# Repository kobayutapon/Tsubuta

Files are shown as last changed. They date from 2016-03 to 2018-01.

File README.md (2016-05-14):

# Tsubuta
Tsubuta is IoT device produced by GDG Shinshu

## Presentation
* [Presentation Document](./Document/Tsubuta_Presentation.pdf.pdf)

## Hardware Information  
* [Hardware Specification](./Hardware/BoardSpec.md)
* [Board schematic](./Hardware/Tsubuta_Schematic.pdf)
* [Firmware](./Hardware/Arduino/Tsubuta_AddOnBoard/Tsubuta_AddOnBoard.ino)

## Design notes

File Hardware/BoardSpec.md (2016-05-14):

# つぶ田 Add-On ボード仕様
## Hardware
* Arduino互換　ATMega328P
* 外部I/F
 I2C/UART(Arduino)/UART(Raspberry Pi)

### EEPROM 仕様
|Address|Description|
|:---|-----|
|00h | Version. if 0xff, value is not set.|
|01h | Power On Mode : 0 - auto power off / 1 : auto power on |  
|02h/03h/04h/05h  | Interval Timer Count |
|06h | GPIO0 Setting 0:Out / 1:In / 2:In-Pullup |
|07h | GPIO1 Setting 0:Out / 1:In / 2:In-Pullup |
|08h | GPIO2 Setting 0:Out / 1:In / 2:In-Pullup |
|09h | GPIO3 Setting 0:Out / 1:In / 2:In-Pullup |

### GPIO Pin assign
|Port|Pin No.|Description|
|:---|---|---|
|TSUBUTA_UART_RXD  | 0 |  PD0 |
|TSUBUTA_UART_TXD  | 1 |  PD1 |
|TSUBUTA_RPIPOWER  | 3 |  PD3 (O)  Raspberry Pi Power On/Off |
|TSUBUTA_GPI_POFF  | 4 |  PD4 (I) Shutdown signal from Raspberry Pi |
|TSUBUTA_GPIO0 | 5 |  PD5  PWM |
|TSUBUTA_GPIO1 | 6 |  PD6  PWM |
|TSUBUTA_GPIO2 | 7 |  PD7 |
|TSUBUTA_GPIO3 | 8 |  PB0 |
|TSUBUTA_RPI_INT | 9 |  PB1 (O) Interrupt signal to Raspberry Pi |
|TSUBUTA_RTC_INT | 10 |  PB2 (I) Interrupt signal from DS1307(RTC Clock) |
|TSUBUTA_AD0 | A0  |  PC0 |
|TSUBUTA_AD1 | A1  |  PC1 |
|TSUBUTA_AD2 | A2  |  PC2 |
|TSUBUTA_AD3 | A3  |  PC3 |

## Firmware仕様

### I/F
* I2C
Slave Address 0x08  
Raspberry Piと接続。電源は3.3V。  

### プログラム仕様
#### I2C Command一覧  

|Command|Parameter|Length|Decsription|
|:---|---|---|---|
| 0x00 | N/A | 0x01 | Get Baord Information |
| 0x01 | Time(4Byte)| 0x05 | Set Interval Timer |
| 0x02 | N/A | 0x01 | RPi Power Off |
| 0x0F | N/A | 0x01 | Save settings to EEPROM |
| 0x10 | State ( 1Byte) |0x02| Set GPIO1 State|
| 0x11 | State ( 1Byte) |0x02| Set GPIO2 State|
| 0x12 | State ( 1Byte) |0x02| Set GPIO3 State|
| 0x13 | State ( 1Byte) |0x02| Set GPIO4 State|
| 0x20 | H/L ( 1Byte) | 0x02 | Set GPO1 H/L |
| 0x21 | H/L ( 1Byte) | 0x02 | Set GPO2 H/L |
| 0x22 | H/L ( 1Byte) | 0x02 | Set GPO3 H/L |
| 0x23 | H/L ( 1Byte) | 0x02 | Set GPO4 H/L |
| 0x30 | H/L ( 1Byte) | 0x02 | Get GPI1 |
| 0x31 | H/L ( 1Byte) | 0x02 | Get GPI2 |
| 0x32 | H/L ( 1Byte) | 0x02 | Get GPI3 |
| 0x33 | H/L ( 1Byte) | 0x02 | Get GPI4 |
| 0x40 | N/A | 0x01 | Get ADC1 |
| 0x41 | N/A | 0x01 | Get ADC2 |
| 0x42 | N/A | 0x01 | Get ADC3 |
| 0x43 | N/A | 0x01 | Get ADC4 |

#### Command詳細
* ボード情報取得(0x00)  
FWのVersion情報を取得する。コマンド実行例をいかに示す。
```
root@raspberrypi:/home/pi# i2cget -y 1 0x08 0x00
0x01
```

* 起動時間間隔設定(0x01)  
自動起動の間隔を秒単位で指定する。指定は4バイトで秒単位で指定する。
```
i2cset -y 1 0x08 0x01 0x00 0x00 0x00 0xff i
```

* 起動時間間隔設定(0x02)  
Raspberry Piの電源をOFFにする。
```
i2cset -y 1 0x08 0x02
```

## Raspberry Piからの制御例
### i2ctoolsを使う場合
* Inerval Timerの設定
```
i2cset 1 0x08 0x01 0x00 0x00 0x00 0xff i
```

* EEPROMの保存
```
i2cset 1 0x08 0x0F
```

### GPIOの制御
GPIO経由で電源を切るには以下のコマンドを実行する。  

```
echo 17 > /sys/class/gpio/export
echo out > /sys/class/gpio/gpio17/direction
echo 1 > /sys/class/gpio/gpio17/value
```

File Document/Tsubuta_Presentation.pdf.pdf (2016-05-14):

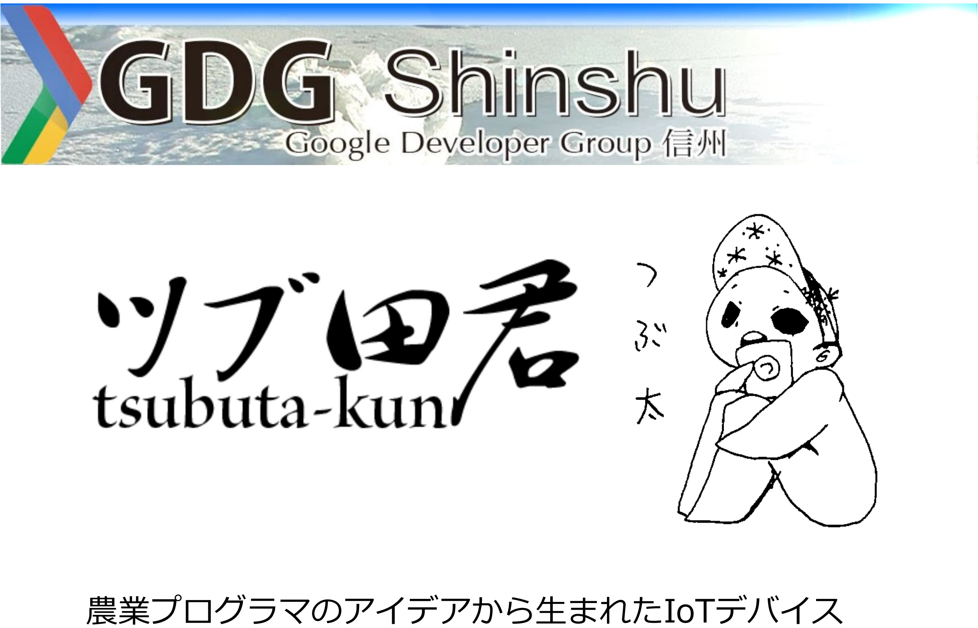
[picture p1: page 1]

## 農業プログラマのアイデアから生まれたIoTデバイス

農家やってると
・朝早く田んぼ見に行かなきゃいけないのよ。。。4時とかなｗ ・田んぼ、遠いんだよ。。。２ｋｍとか普通に離れてる。。。 ・必要な時だけいきたいんだよー！！
という悩みがあるので作りました。
特徴
・Raspberry Piと3G USB通信モデムを使って呟きます。 ・独自の電源制御基板で省電力。5V 2500mAhのバッテリーなら1日1回の つぶやきで三か月くらいは持ちます。
・材料は塩ビパイプで構成。防水も行けます。

## なんで作ったの？

### 畑に設置した様子

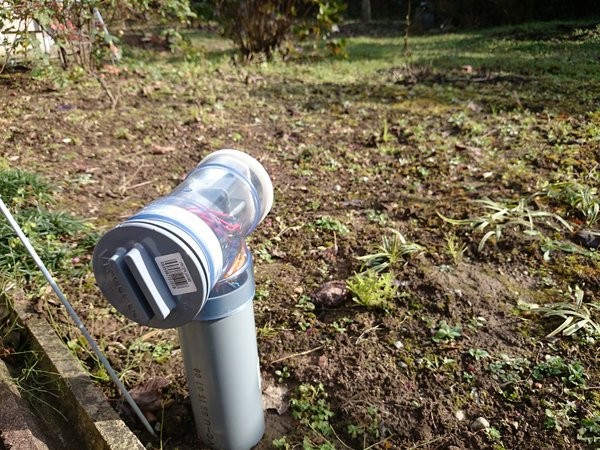
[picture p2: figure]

### つぶ田くん システムブロック図

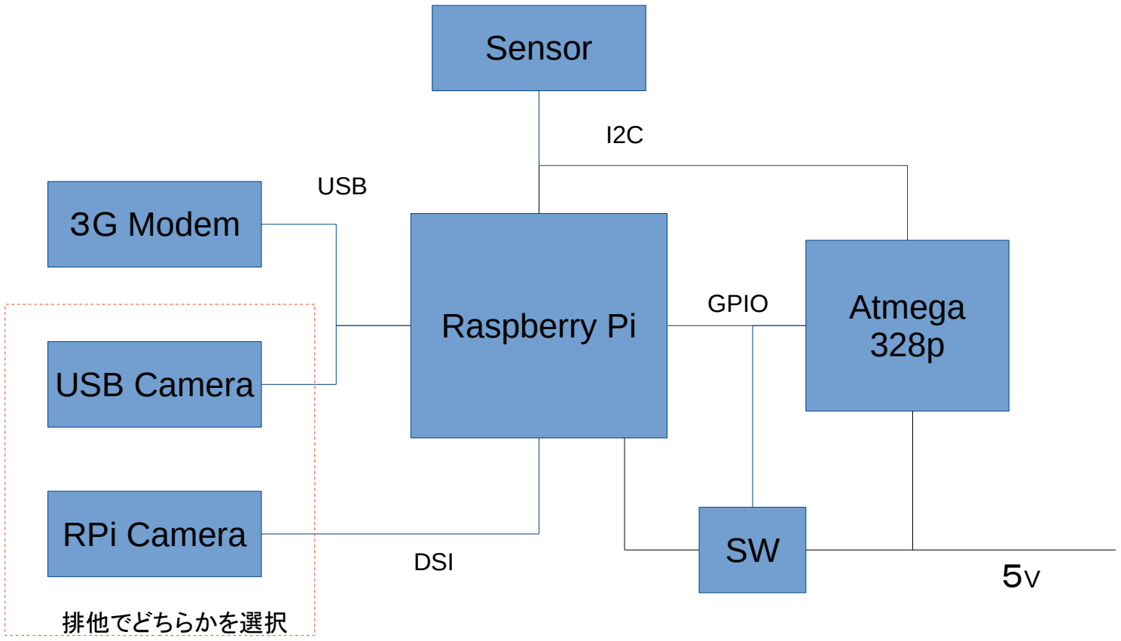
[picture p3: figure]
Raspberry Pi; ３G Modem; USB Camera; RPi Camera; Atmega 328p; Sensor; USB; GPIO; DSI; 排他でどちらかを選択

### 設定方法 Google Spreadsheetsを編集するだけ！

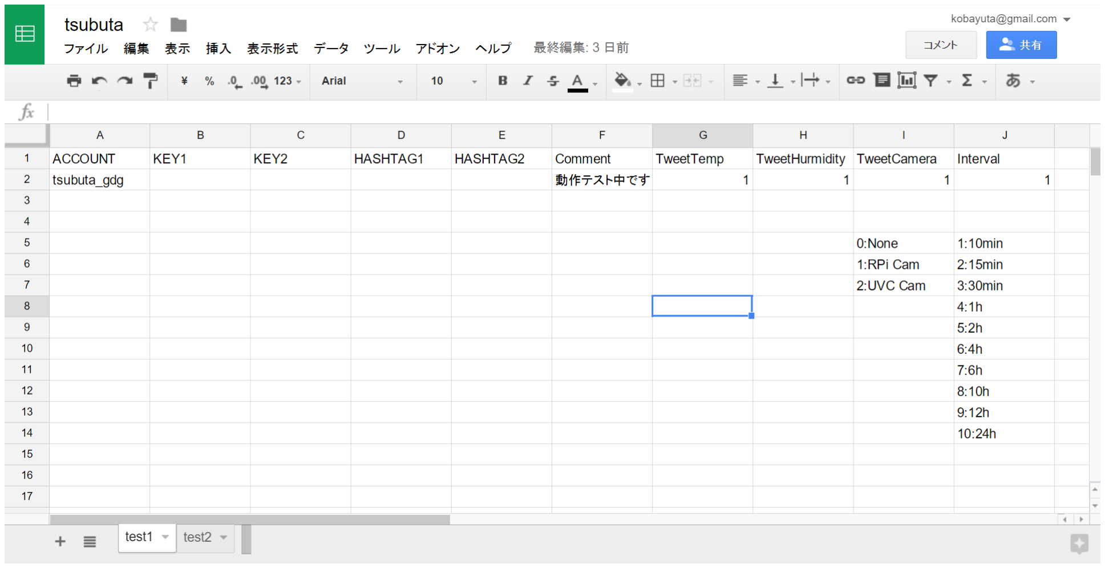
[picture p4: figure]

### 設定時間ごとに呟きます

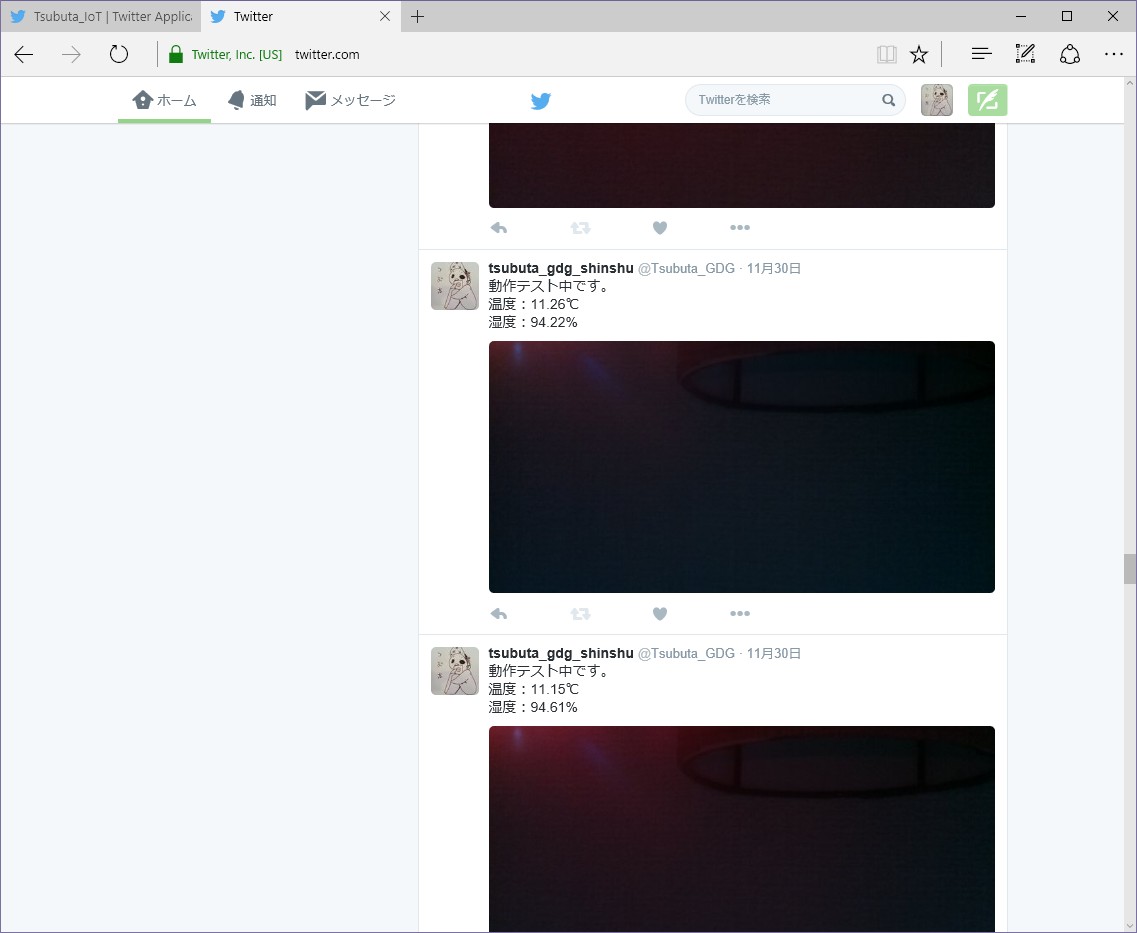
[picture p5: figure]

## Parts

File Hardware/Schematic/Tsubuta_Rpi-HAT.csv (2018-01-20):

Reference | Value | Footprint | Datasheet
C1 | 0.1uF | Capacitors_SMD:C_0805_HandSoldering
C2 | 22pF | Capacitors_SMD:C_0805_HandSoldering
C3 | 22pF | Capacitors_SMD:C_0805_HandSoldering
C4 | 0.33uF | Capacitors_SMD:C_0805_HandSoldering
C5 | 22uF | Capacitors_SMD:C_0805_HandSoldering
C6 | 2.2uF | Capacitors_SMD:C_0805_HandSoldering
J1 | Conn_01x04 | Pin_Headers:Pin_Header_Straight_1x04_Pitch2.54mm
J10 | CN_I2C | Pin_Headers:Pin_Header_Straight_1x04_Pitch2.54mm
J11 | ADC0 | Pin_Headers:Pin_Header_Straight_1x03_Pitch2.54mm
J12 | ADC1 | Pin_Headers:Pin_Header_Straight_1x03_Pitch2.54mm
J13 | ADC2 | Pin_Headers:Pin_Header_Straight_1x03_Pitch2.54mm
J14 | ADC3 | Pin_Headers:Pin_Header_Straight_1x03_Pitch2.54mm
J15 | BOOTMODE | Pin_Headers:Pin_Header_Straight_2x05_Pitch2.54mm
J2 | RPi_GPIO | RPi_Hat:Pin_Header_Straight_2x20
J3 | CN_ICSP | Pin_Headers:Pin_Header_Straight_2x03_Pitch2.54mm
J4 | Jack-DC | Connect:BARREL_JACK
J5 | GPIO0 | Pin_Headers:Pin_Header_Straight_1x03_Pitch2.54mm
J6 | GPIO1 | Pin_Headers:Pin_Header_Straight_1x03_Pitch2.54mm
J7 | GPIO2 | Pin_Headers:Pin_Header_Straight_1x03_Pitch2.54mm
J8 | GPIO3 | Pin_Headers:Pin_Header_Straight_1x03_Pitch2.54mm
J9 | Conn_01x03 | Pin_Headers:Pin_Header_Straight_1x03_Pitch2.54mm
Q1 | 2SC3325-Y | TO_SOT_Packages_SMD:SC-59_Handsoldering
Q2 | IRLML6402(SOT-23) | TO_SOT_Packages_SMD:SOT-23_Handsoldering
R1 | 10K | Resistors_SMD:R_0805_HandSoldering
R10 | 1K | Resistors_SMD:R_0805_HandSoldering
R11 | 10K | Resistors_SMD:R_0805_HandSoldering
R12 | 10K | Resistors_SMD:R_0805_HandSoldering
R13 | 10K | Resistors_SMD:R_0805_HandSoldering
R14 | 1.8K | Resistors_SMD:R_0805_HandSoldering
R15 | 3.3K | Resistors_SMD:R_0805_HandSoldering
R2 | 10K | Resistors_SMD:R_0805_HandSoldering
R3 | 10K | Resistors_SMD:R_0805_HandSoldering
R4 | 10K | Resistors_SMD:R_0805_HandSoldering
R5 | 10K | Resistors_SMD:R_0805_HandSoldering
R6 | 10K | Resistors_SMD:R_0805_HandSoldering
R7 | 10K | Resistors_SMD:R_0805_HandSoldering
R8 | 10K | Resistors_SMD:R_0805_HandSoldering
R9 | 10K | Resistors_SMD:R_0805_HandSoldering
SW1 | SW_RST | Buttons_Switches_THT:SW_PUSH_6mm
U1 | ATMEGA328P-AU | Housings_QFP:TQFP-32_7x7mm_Pitch0.8mm
U2 | NJM2884U1 | TO_SOT_Packages_SMD:SOT-89-5_Housing_Handsoldering
Y1 | 16MHz | Crystals:Crystal_HC49-U_Vertical

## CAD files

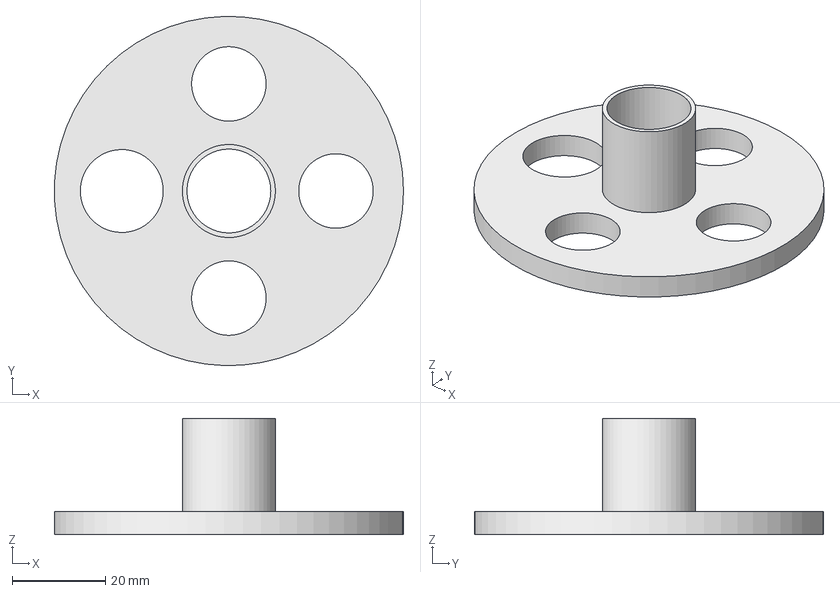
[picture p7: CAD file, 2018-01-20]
Hardware/Mecha/Tsubuta_Sensor_Holder.FCStd
74.9 x 75.0 x 25.0 mm

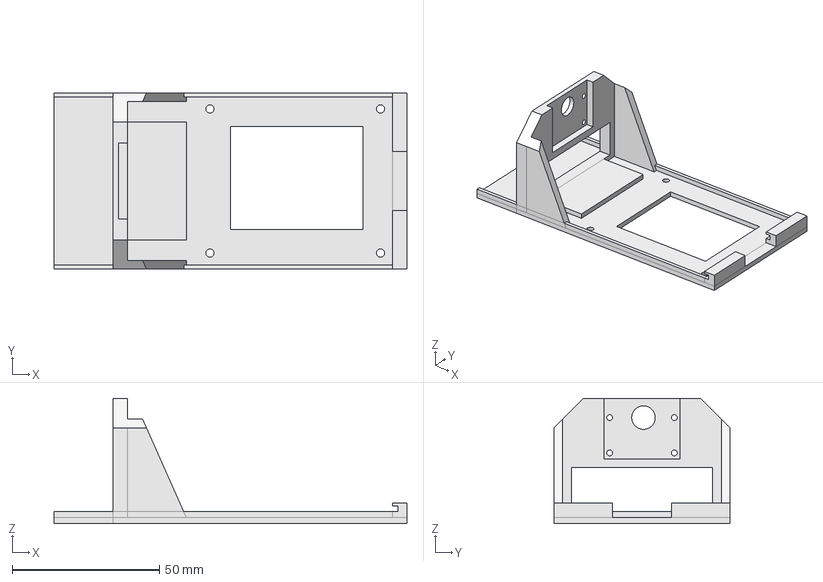
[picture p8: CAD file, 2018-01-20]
Hardware/Mecha/Tsubuta_Base_Rev2.FCStd
120.0 x 60.0 x 42.5 mm

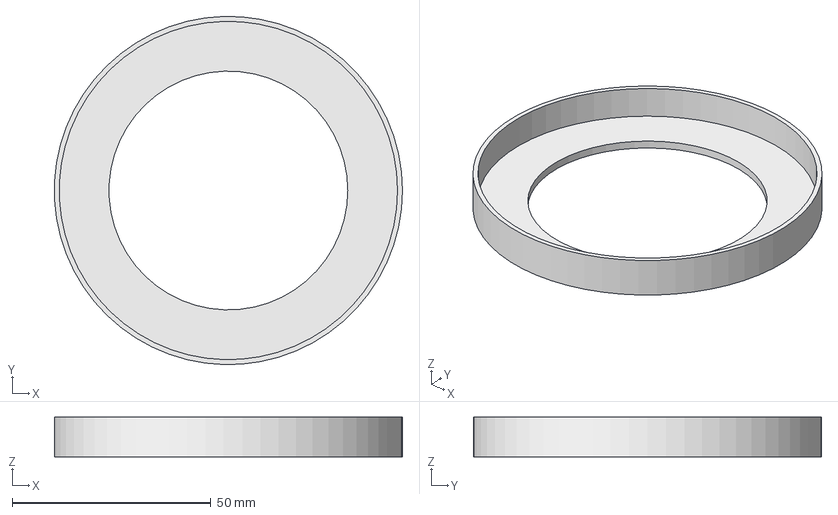
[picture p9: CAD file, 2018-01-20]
Hardware/Mecha/Tsubuta_Lens_Cover.FCStd
87.4 x 87.5 x 10.0 mm

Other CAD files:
Hardware/Mecha/Tsubuta_Base_Rev2.stl
Hardware/Mecha/Tsubuta_Sensor_Holder.stl

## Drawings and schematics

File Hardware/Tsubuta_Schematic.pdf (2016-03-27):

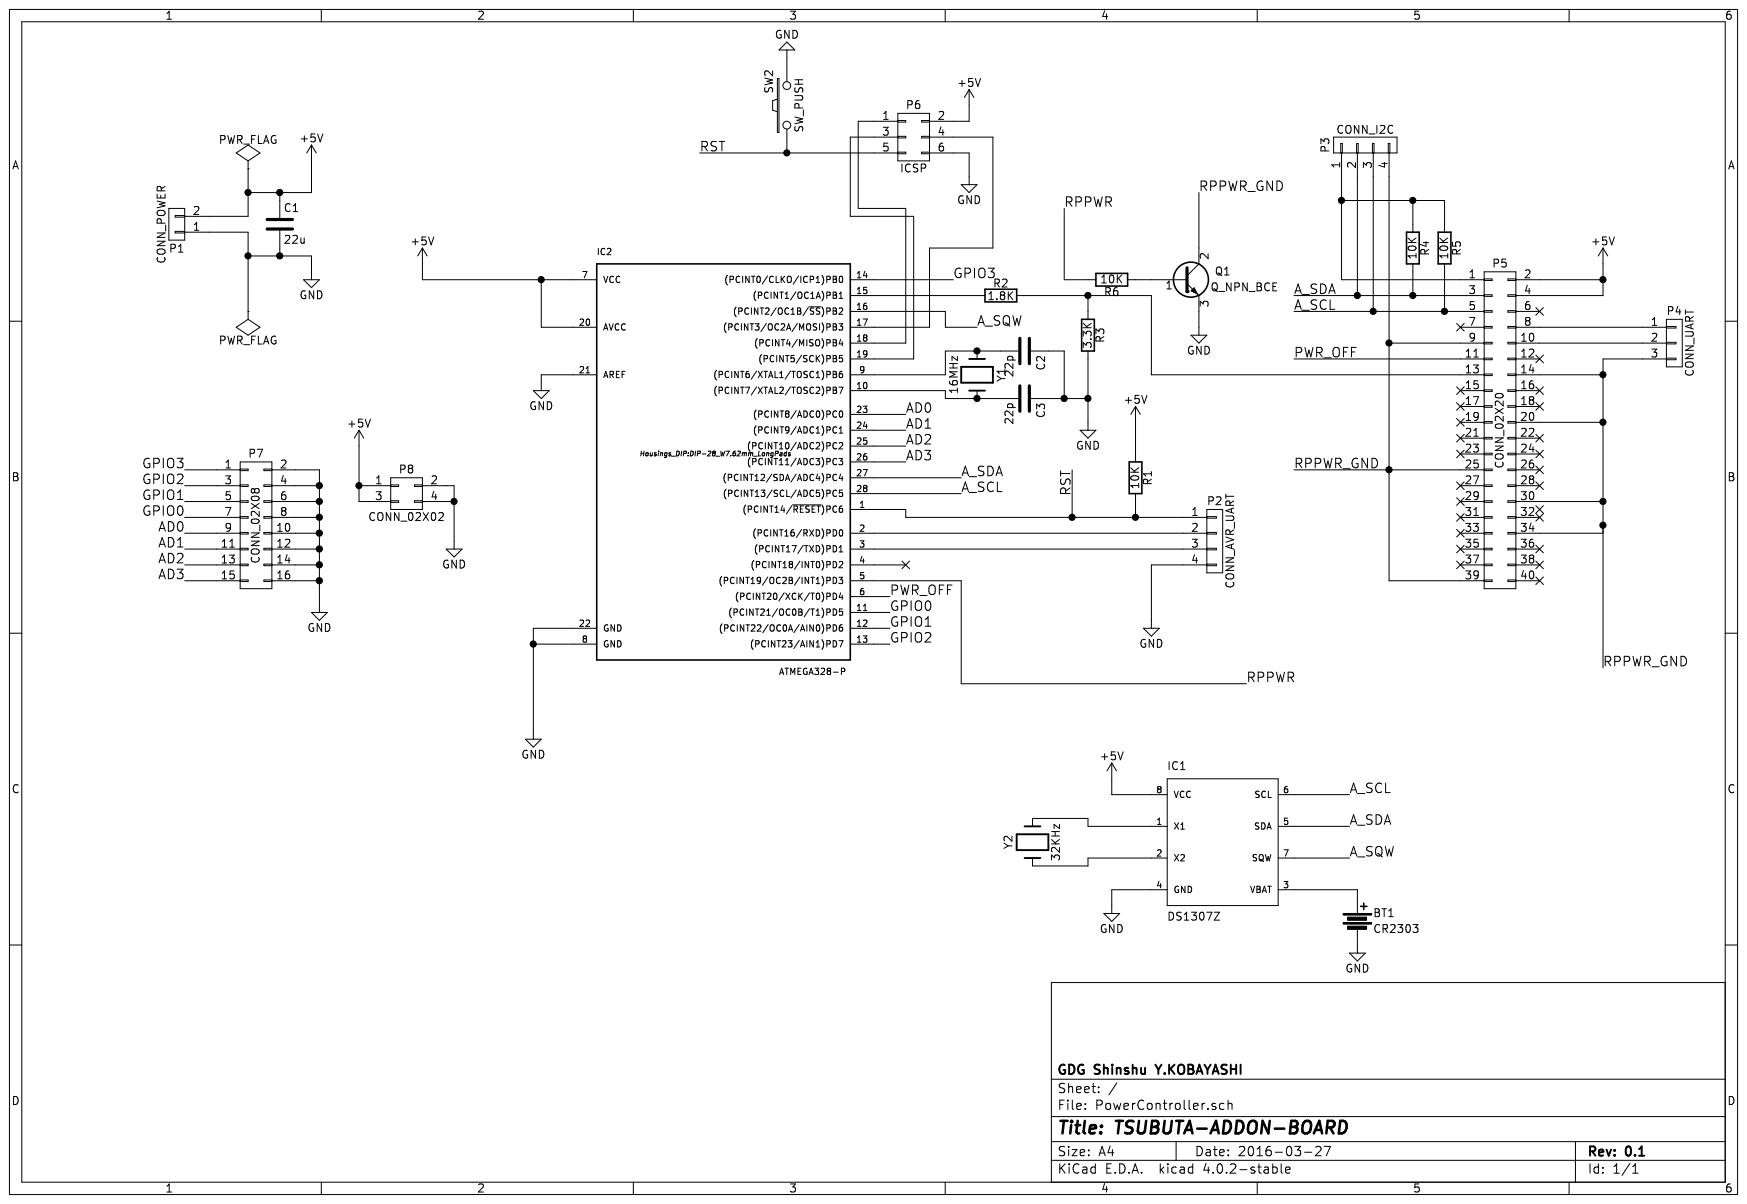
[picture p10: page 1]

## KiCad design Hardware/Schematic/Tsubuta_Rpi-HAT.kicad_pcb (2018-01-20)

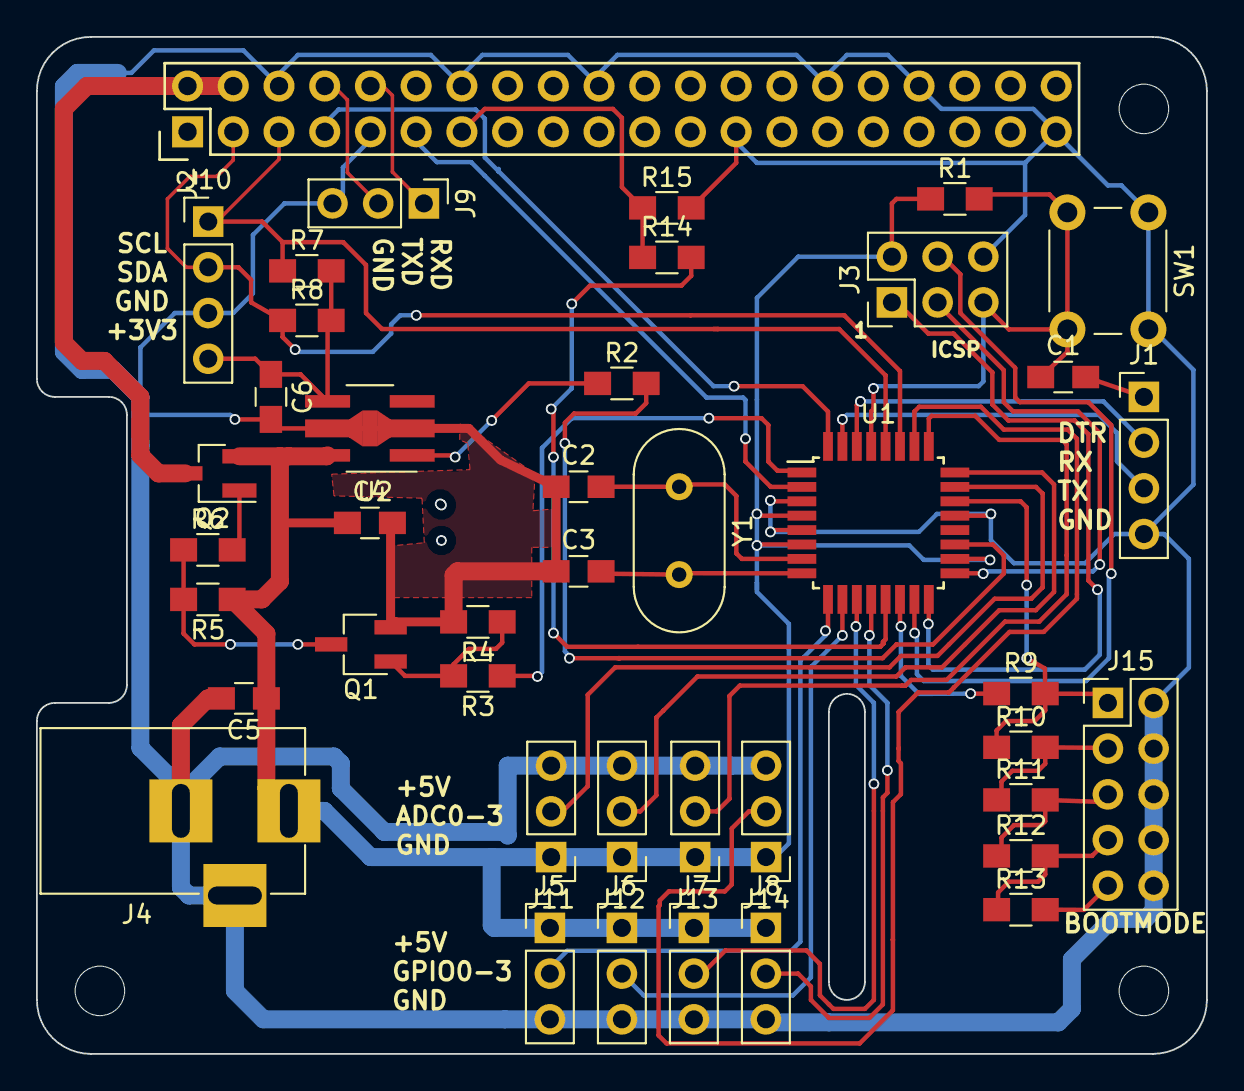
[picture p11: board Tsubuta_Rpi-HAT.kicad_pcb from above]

Board: 2 copper layers, 65.0 x 56.5 mm, 42 parts (0 on the bottom side), 41 nets.

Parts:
C1: 0.1uF; C_0805_HandSoldering
C2, C3: 22pF; C_0805_HandSoldering
C4: 0.33uF; C_0805_HandSoldering
C5: 22uF; C_0805_HandSoldering
C6: 2.2uF; C_0805_HandSoldering
J1: Conn_01x04; Pin_Header_Straight_1x04_Pitch2.54mm
J2: RPi_GPIO; Pin_Header_Straight_2x20
J3: CN_ICSP; Pin_Header_Straight_2x03_Pitch2.54mm
J4: Jack-DC; BARREL_JACK
J5: GPIO0; Pin_Header_Straight_1x03_Pitch2.54mm
J6: GPIO1; Pin_Header_Straight_1x03_Pitch2.54mm
J7: GPIO2; Pin_Header_Straight_1x03_Pitch2.54mm
J8: GPIO3; Pin_Header_Straight_1x03_Pitch2.54mm
J9: Conn_01x03; Pin_Header_Straight_1x03_Pitch2.54mm
J10: CN_I2C; Pin_Header_Straight_1x04_Pitch2.54mm
J11: ADC0; Pin_Header_Straight_1x03_Pitch2.54mm
J12: ADC1; Pin_Header_Straight_1x03_Pitch2.54mm
J13: ADC2; Pin_Header_Straight_1x03_Pitch2.54mm
J14: ADC3; Pin_Header_Straight_1x03_Pitch2.54mm
J15: BOOTMODE; Pin_Header_Straight_2x05_Pitch2.54mm
Q1: 2SC3325-Y; SC-59_Handsoldering
Q2: IRLML6402(SOT-23); SOT-23_Handsoldering
R1, R2, R3, R4, R5, R6, R7, R8, R9, R11, R12, R13: 10K; R_0805_HandSoldering
R10: 1K; R_0805_HandSoldering
R14: 1.8K; R_0805_HandSoldering
R15: 3.3K; R_0805_HandSoldering
SW1: SW_RST; SW_PUSH_6mm
U1: ATMEGA328P-AU; TQFP-32_7x7mm_Pitch0.8mm
U2: NJM2884U1; SOT-89-5_Housing_Handsoldering
Y1: 16MHz; Crystal_HC49-U_Vertical

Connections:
3V3_ENB: R2.2, U1.19
#ARD_SS: R9.1, U1.14
#RST: C1.1, J3.5, R1.2, SW1.2, U1.29
+3V3: C6.1, J10.4, R7.2, R8.2, U2.4
+5V: C4.1, C5.1, J3.2, J4.1, J5.1, J6.1, J7.1, J8.1, J11.1, J12.1, J13.1, J14.1, Q2.2, R1.1, R5.1, U1.4, U1.6, U1.18, U2.5
ADC0: J11.2, U1.23
ADC1: J12.2, U1.24
ADC2: J13.2, U1.25
ADC3: J14.2, U1.26
ARD_INT_3V3: J2.13, R14.1, R15.1
ARD_INT_5V: R14.2, U1.13
ARD_MISO: J3.1, U1.16
ARD_MOSI: J3.4, U1.15
ARD_RX: J1.2, U1.30
ARD_SCK: J3.3, U1.17
ARD_SCL: J2.5, J10.1, R7.1, U1.28
ARD_SDA: J2.3, J10.2, R8.1, U1.27
ARD_TX: J1.3, U1.31
ARD_XTAL1: C2.2, U1.7, Y1.1
ARD_XTAL2: C3.2, U1.8, Y1.2
BOOTMODE: J15.1, R9.2, R10.1, U1.22
GND: C2.1, C3.1, C4.2, C5.2, C6.2, J1.4, J2.6, J2.9, J2.14, J2.20, J2.25, J2.30, J2.34, J2.39, J3.6, J4.2, J4.3, J5.3, J6.3, J7.3, J8.3, J9.3, J10.3, J11.3, J12.3, J13.3, J14.3, J15.2, J15.4, J15.6, J15.8, J15.10, Q1.2, R4.2, R15.2, SW1.1, U1.3, U1.5, U1.21, U2.2
GPIO0: J5.2, U1.9
GPIO1: J6.2, U1.10
GPIO2: J7.2, U1.11
GPIO3: J8.2, U1.12
unnamed: C1.2, J1.1
unnamed: J15.3, R10.2, R11.1
unnamed: J15.5, R11.2, R12.1
unnamed: J15.7, R12.2, R13.1
unnamed: J15.9, R13.2
unnamed: Q1.1, R3.2, R4.1
unnamed: Q1.3, R5.2, R6.1
unnamed: Q2.1, R6.2
unnamed: R2.1, U2.1
PWR_OFF: J2.11, U1.2
RPI_5V: J2.2, J2.4, Q2.3
RPI_INT: J2.7, U1.32
RPI_RXD: J2.10, J9.1
RPI_TXD: J2.8, J9.2
RPPWR: R3.1, U1.1

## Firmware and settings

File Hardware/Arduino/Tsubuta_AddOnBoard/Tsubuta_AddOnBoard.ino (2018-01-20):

// ------------------------------------------
//   Tsubuta Add-on board Ver.2 firmware
// ------------------------------------------
#include <Arduino.h>
#include <avr/sleep.h>
#include <avr/wdt.h>
#include <EEPROM.h>
#include <Wire.h>

// ------- for Standby mode
#ifndef cbi
#define cbi(sfr, bit) (_SFR_BYTE(sfr) &= ~_BV(bit))
#endif
#ifndef sbi
#define sbi(sfr, bit) (_SFR_BYTE(sfr) |= _BV(bit))
#endif


#define TSUBUTA_RPIPOWER  3     //  PD3 (O)  Raspberry Pi Power On/Off
#define TSUBUTA_GPI_POFF  4     //  PD4 (I) Shutdown signal from Raspberry Pi

// ---------------------------------------
//     for I2C
// ---------------------------------------
#define I2C_SLAVE_ADDRESS   8


// ------- Command
#define COMMAND_CLEARTIMER        0x00
#define COMMAND_SETINTERVALTIME   0x01
#define COMMAND_POWEROFF          0x02
#define COMMAND_GET_TIME          0x10
#define COMMAND_GET_RUN_TIME      0x11
#define COMMAND_GET_PWRON_CNT     0x12

#define COMMAND_UNKNOWN           0xFF


//#define BATTERY_ALERT_THREAD      3000
#define BATTERY_ALERT_THREAD      30000
//#define BATTERY_ALERT_THREAD      180

bool g_bPowerOn = true;
unsigned long g_PwrOnCount;
unsigned long g_lRunTime;       // Raspberry Pi側の連続通電時間（秒）
unsigned long g_TimerCounter;   // Interval Timer Counter
unsigned long g_WdtCounter;     // Watch dog Timer Counter = Arduino側の連続通電時間（秒）
unsigned long g_IntervalTime = 900;

typedef struct _command_info_ {
  unsigned char m_ucCommand;
  unsigned char m_ucLength;
  bool          m_bReply;
} COMMAND_TABLE;

typedef struct _buffer_tag_ {
  unsigned char   len;
  unsigned char   rdptr;
  unsigned char   wrptr;  
  unsigned char   buff[32];
} CMD_BUFFER;

CMD_BUFFER    g_bufI2CRecive;
CMD_BUFFER    g_bufI2CSend;

typedef struct _i2c_command_tag_ {
  unsigned char   ucCmd;
  char            cParamLen;
  char            cLen;
  unsigned char   ucBuff[16];
} RCVCMD;

volatile RCVCMD g_RcvCmd;

const COMMAND_TABLE   g_cCommandInfo[] = {
  { 0x00 , 0x01 , true },     // Get Baord Information 
  { 0x01 , 0x05 , false },    // Set Interval Timer |
  { 0x02 , 0x01 , false },    // RPi Power Off |
  { 0x10 , 0x01 , true },    // RPi Power Off |
  { 0x11 , 0x01 , true },    // RPi Power Off |
  { 0x12 , 0x01 , true },    // RPi Power Off |
  { 0xFF , 0xFF, false },   
};


// ====================================================
//   I2Cの送受信バッファ回り
// ====================================================
void PutBufferStatus(CMD_BUFFER *pPtr)
{
  Serial.print("len:"); Serial.println(pPtr->len);
  Serial.print("wptr:"); Serial.println(pPtr->wrptr);
  Serial.print("rptr:"); Serial.println(pPtr->rdptr);
}

void InitCommandBuffer(CMD_BUFFER *pPtr)
{
  pPtr->len = 0;
  pPtr->rdptr = 0;
  pPtr->wrptr = 0;
//  memset((void *)pPtr->buff, 0, sizeof(unsigned char)*32 );

  PutBufferStatus(pPtr);
}

bool SetCommandBuffer( CMD_BUFFER *pPtr, unsigned char c )
{
  Serial.print("chr:"); Serial.println(c);
  
  if ( pPtr->len >= 32 ) return false;    // バッファがいっぱいな場合
  pPtr->buff[pPtr->wrptr] = c;
  pPtr->wrptr++;
  pPtr->wrptr &= 31;
  pPtr->len++;
  PutBufferStatus(pPtr);
  
  return true;
  
}

bool GetCommandBuffer( CMD_BUFFER *pPtr, unsigned char *c , int *pLen )
{
  if ( pPtr->len <= 0 ) return false;    // バッファが空な場合

  *pLen = pPtr->len;
  while( pPtr->len > 0 ) {
    *c++ = pPtr->buff[pPtr->rdptr];
    pPtr->rdptr++;
    pPtr->rdptr &= 31;
    pPtr->len--;

    PutBufferStatus(pPtr);
  }
  
  return true;
  
}

bool IsCommandBufferEmpty( CMD_BUFFER *pPtr )
{
  PutBufferStatus(pPtr);
  return ( pPtr->len <= 0 ) ? true : false ;
}

void ClearCommand( RCVCMD *pCmd )
{
  pCmd->ucCmd = 0;
  pCmd->cParamLen = 0;
  pCmd->cLen = -1;
  memset( (void *)pCmd->ucBuff, 0, sizeof(unsigned char)*16 );

}

int GetCmdParamLen( unsigned char ucCmd )
{
  int nRet = -1;
  int nIndex = 0;
  
  while(g_cCommandInfo[nIndex].m_ucCommand != COMMAND_UNKNOWN ) {
    if ( g_cCommandInfo[nIndex].m_ucCommand == ucCmd ) {
      nRet = g_cCommandInfo[nIndex].m_ucLength - 1;
      break;
    }
    nIndex++;
  }

  return nRet;
}


void ParseCommand( RCVCMD *pCmd )
{
  unsigned char ctmp;
  unsigned long ltmp;
  
  switch( pCmd->ucCmd ) {
    case COMMAND_CLEARTIMER:
      g_TimerCounter = 1;
      Serial.print("Current Timer Count:");
      Serial.println(g_TimerCounter);
      g_TimerCounter = 1;
      Serial.print("Cleared Timer Count:");
      Serial.println(g_TimerCounter);
      break;

    case COMMAND_SETINTERVALTIME:
      Serial.println("CMD:SETINTERVAL");
      ltmp = pCmd->ucBuff[0]; ltmp <<= 8;
      ltmp |= pCmd->ucBuff[1]; ltmp <<= 8;
      ltmp |= pCmd->ucBuff[2]; ltmp <<= 8;
      ltmp |= pCmd->ucBuff[3];
      g_IntervalTime = ltmp;
      Serial.print("Interval Time:");
      Serial.println(g_IntervalTime);
      break;

    case COMMAND_GET_TIME:
      Serial.println("CMD:GET_TIME");
      SetCommandBuffer(&g_bufI2CSend, (g_WdtCounter >> 24) & 0xff );
      SetCommandBuffer(&g_bufI2CSend, (g_WdtCounter >> 16) & 0xff);
      SetCommandBuffer(&g_bufI2CSend, (g_WdtCounter >>  8) & 0xff);
      SetCommandBuffer(&g_bufI2CSend, (g_WdtCounter >>  0) & 0xff);
      break;

    case COMMAND_GET_RUN_TIME:
      Serial.println("CMD:GET_RUN_TIME");
      SetCommandBuffer(&g_bufI2CSend, (g_lRunTime >> 24) & 0xff );
      SetCommandBuffer(&g_bufI2CSend, (g_lRunTime >> 16) & 0xff);
      SetCommandBuffer(&g_bufI2CSend, (g_lRunTime >>  8) & 0xff);
      SetCommandBuffer(&g_bufI2CSend, (g_lRunTime >>  0) & 0xff);
      break;

    case COMMAND_GET_PWRON_CNT:
      SetCommandBuffer(&g_bufI2CSend, (g_PwrOnCount >> 24) & 0xff );
      SetCommandBuffer(&g_bufI2CSend, (g_PwrOnCount >> 16) & 0xff);
      SetCommandBuffer(&g_bufI2CSend, (g_PwrOnCount >>  8) & 0xff);
      SetCommandBuffer(&g_bufI2CSend, (g_PwrOnCount >>  0) & 0xff);
      break;      
      
    default:
      break;  
  }
}


// --------------------------------
//   Interupt handler
// --------------------------------
// Interrupt handler for I2C

bool g_bRequestEvent;

void receiveEvent( int howMany  )
{
  int c;
  int len;
  
  while(Wire.available()) {
    g_bRequestEvent = false;
    c = Wire.read();
    Serial.print("I2C:Rcv ");
    Serial.println(c, HEX);
    if ( g_RcvCmd.cLen < 0 ) {
      g_RcvCmd.ucCmd = (unsigned char)c;
      if ( (g_RcvCmd.cParamLen = GetCmdParamLen(g_RcvCmd.ucCmd)) >= 0 ) {
        g_RcvCmd.cLen = 0;
      }
      Serial.print("Command :");
      Serial.println(g_RcvCmd.ucCmd,HEX);
      Serial.print("Param Len :");
      Serial.println(g_RcvCmd.cParamLen,HEX);
      
      if ( g_RcvCmd.cParamLen == 0x00 ) {
        Serial.println("Parse command");
        ParseCommand((RCVCMD *)&g_RcvCmd);
        ClearCommand((RCVCMD *)&g_RcvCmd);        
      }
    } else {
      g_RcvCmd.ucBuff[g_RcvCmd.cLen] = c;
      g_RcvCmd.cLen++;
      Serial.print("Rcv Len :");
      Serial.println(g_RcvCmd.cLen,HEX);
      if ( g_RcvCmd.cLen >= g_RcvCmd.cParamLen ) {
        // パラメータがすべてそろったのでコマンド解析を行う
        Serial.println("Parse command");
        ParseCommand((RCVCMD *)&g_RcvCmd);
        ClearCommand((RCVCMD *)&g_RcvCmd);
      }
    }
  }  
}

void requestEvent( )
{
  unsigned char c;
  unsigned char buff[32];
  int len;
  
  Serial.println("I2C:Send Request ");
  if ( g_bufI2CSend.len > 0 ) {
    if ( true == GetCommandBuffer( &g_bufI2CSend, buff, &len )) {
      Wire.write(buff, len );
    }
  }
}


void PowerOn()
{
#if 0
  Serial.println("P1");
    delay(10);
  for( int i=0; i<100; i++ ) {
    digitalWrite( TSUBUTA_RPIPOWER, HIGH );
    digitalWrite( TSUBUTA_RPIPOWER, LOW );
    delay(20);
  }

  Serial.println("P2");
    delay(10);
  for( int i=0; i<100; i++ ) {
    digitalWrite( TSUBUTA_RPIPOWER, HIGH );
    digitalWrite( TSUBUTA_RPIPOWER, LOW );
    delay(10);
  }
  
  Serial.println("P3");
    delay(10);
  for( int i=0; i<50; i++ ) {
    digitalWrite( TSUBUTA_RPIPOWER, HIGH );
    digitalWrite( TSUBUTA_RPIPOWER, LOW );
    delay(5);
  }

  Serial.println("P4");
    delay(10);
  for( int i=0; i<50; i++ ) {
    digitalWrite( TSUBUTA_RPIPOWER, HIGH );
    digitalWrite( TSUBUTA_RPIPOWER, LOW );
    delay(1);
  }
  
  Serial.println("P5");
    delay(10);
  for( int i=0; i<50; i++ ) {
    digitalWrite( TSUBUTA_RPIPOWER, HIGH );
    digitalWrite( TSUBUTA_RPIPOWER, LOW );
  }
  
#endif

  Serial.println("P6");
  delay(10);
  digitalWrite( TSUBUTA_RPIPOWER, HIGH );
  g_bPowerOn = true;  
}

// ----------------------------------------------

void setup() {
  // put your setup code here, to run once:
  // シリアルポート初期化:
  Serial.begin(115200);
  Serial.println("Tsubuta add-on board.");
  Serial.println(MCUSR,HEX);

  Serial.println("Initialize GPIO.");
  pinMode( TSUBUTA_RPIPOWER, OUTPUT );          // Raspberry Pi On/Off
  pinMode( TSUBUTA_GPI_POFF, INPUT  );          // Interrupt signal from Raspberry Pi
  pinMode( 10, OUTPUT );                        // BOOTMODE
  pinMode( 9, OUTPUT );                         // BATTERY ALERT(to RPi)
  digitalWrite( TSUBUTA_RPIPOWER, LOW );
  digitalWrite( 9, LOW );

#if 1
  // Set I2C
  // TWIのライブラリの中で5Vにプルアップされてしまう。ここでPullUpをやめているけど、
  // 瞬間的に５Vかかって壊れる可能性あるのでライブラリの中を修正したほうが良い。
  // \hardware\arduino\avr\libraries\Wire\utility\twi.cの
  // activate internal pullups for twi.
  //  digitalWrite(SDA, 1);
  //  digitalWrite(SCL, 1);
  // の部分をコメントアウトしてプルアップ無効化すること
  Serial.println("Initialize I2C.");
  Wire.begin(I2C_SLAVE_ADDRESS);
  pinMode(SDA, INPUT);
  pinMode(SCL, INPUT);
  
  Wire.onRequest( requestEvent );
  Wire.onReceive( receiveEvent );
#endif

  // Setup System 
  Serial.println("Buffer initialize.");
  InitCommandBuffer(&g_bufI2CRecive);
  InitCommandBuffer(&g_bufI2CSend);
  ClearCommand((RCVCMD*)&g_RcvCmd);
  
  Serial.println("Get Bootmode.");
#if 1
  digitalWrite( 10, HIGH );
  delay(100);
  int v=0;
  v = analogRead(A7);    
  digitalWrite( 10, LOW );
  Serial.println(v);

  // 817    BOOTMODE4
  // 765    BOOTMODE3
  // 680    BOOTMODE2
  
  // 509    BOOTMODE1
  // 0      BOOTMODE0

  if ( v < 500 ) {
//    g_IntervalTime = 900;     // BOOTMODE0 - 15min
//    g_IntervalTime = 844;     // BOOTMODE0 - 15min  
    g_IntervalTime = 563;     // BOOTMODE0 - 10min  
  } 
  else if ( v >= 500 && v < 600 ) {
//    g_IntervalTime = 1687;     // BOOTMODE1 - 30min 1800sec
    g_IntervalTime = 1125;     // BOOTMODE1 - 30min 1800sec
  }
  else if ( v >= 600 && v < 720 ) {
    g_IntervalTime = 3375; // 3600;     // BOOTMODE2 - 1h
  }
  else if ( v >= 720 && v < 790 ) {
    g_IntervalTime = 3375 * 12 ; //3600 * 12;     // BOOTMODE3 - 12h
  }
  else if ( v >= 790  ) {
    g_IntervalTime = 3375 * 24;     // BOOTMODE3 - 24h
  }
#else
  g_IntervalTime = 563;     // BOOTMODE0 - 10min  
#endif

  g_WdtCounter = 0;
  g_lRunTime = 0;
  g_TimerCounter = 1;
  g_PwrOnCount = 1;
  setup_watchdog(6);    // 250msec timer

  // GPIO Output setting
  Serial.println("RPI P.ON.");
  delay(100);
  PowerOn();

}

void loop() {
  // put your main code here, to run repeatedly:

  if ( g_bPowerOn == true ) {
    Serial.print("Runtime :");
    Serial.println(g_lRunTime);
    if ( g_lRunTime > BATTERY_ALERT_THREAD ) {
      Serial.println("Battery down");
      digitalWrite( 9, HIGH );      
    }
    int n = digitalRead(  TSUBUTA_GPI_POFF );
    if ( n == HIGH ) {
      digitalWrite( 9, LOW );
      digitalWrite( TSUBUTA_RPIPOWER, LOW );    
      g_bPowerOn = false;
    }
    delay(500);
  } else {
    system_sleep();
    
    if ( g_TimerCounter == 0 ) {
      Serial.begin(115200);
      Serial.println("Resume.");
      PowerOn();
      g_PwrOnCount++;
    }
  }
}

// --------------------------------
//   for Standby mode Function
// --------------------------------

// Sleep Function
void system_sleep() {                   // システム停止 
  cbi(ADCSRA,ADEN);                     // ADC 回路電源をOFF (ADC使って無くても120μA消費するため）
  set_sleep_mode(SLEEP_MODE_PWR_DOWN);  // パワーダウンモード
//  set_sleep_mode(SLEEP_MODE_PWR_SAVE);  // パワーダウンモード
  sleep_enable();
  sleep_mode();                         // ここでスリープに入る
  sleep_disable();                      // WDTがタイムアップしたらここから動作再開 
  wdt_reset();
  sbi(ADCSRA,ADEN);                     // ADC ON
}  //system_sleep

// 割り込みモードでウォッチドッグタイマーを設定。引数による動作は時間は下記
// 0=16ms, 1=32ms,2=64ms,3=128ms,4=250ms,5=500ms
// 6=1 sec,7=2 sec, 8=4 sec, 9= 8sec
void setup_watchdog(int ii) {           // 
  byte bb;
  int ww;
  if (ii > 9 ) ii=9;
  bb=ii & 7;
  if (ii > 7) bb|= (1<<5);
  bb|= (1<<WDCE);
  ww=bb;
  MCUSR &= ~(1<<WDRF);
  // start timed sequence
  WDTCSR |= (1<<WDCE) | (1<<WDE);
  // set new watchdog timeout value
  WDTCSR = bb;
  WDTCSR |= _BV(WDIE);
}  //setup_watchdog

ISR(WDT_vect) {                         // WDTがタイムアップした時に実行される処理
  g_WdtCounter++; 
//  if ( 0 == ( g_WdtCounter % 4 )) {
    if ( g_bPowerOn == true ) {
      g_lRunTime++;           // 連続通電時間は１秒ごとにカウント
    }
    g_TimerCounter++;
    g_TimerCounter %= g_IntervalTime;
//  }        
}

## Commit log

2016-03-27 新規作成 ・Tsubuta Rev.2向け 回路図/ガーバーデータ Arduino用ソフトウエア
    [PowerController-B_Cu.gbr, PowerController-B_Mask.gbr, PowerController-B_SilkS.gbr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]
2016-03-27 PDF版の回路図を追加
2016-05-13 I2Cコマンド受信処理を修正
2016-05-14 I2Cコマンドを追加・修正
2016-05-14 プレゼンテーション資料を追加
2016-05-14 ファイル削除
2016-05-14 プレゼン資料追加
2018-01-20 3Dプリンタ用のメカデータ追加(FreeCAD用データ)
    [Tsubuta_Base_Rev2.FCStd, Tsubuta_Base_Rev2.stl, Tsubuta_Lens_Cover.FCStd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]
2018-01-20 Tsubuta Rev2 ボード Rpi-HAT外形に準拠 RTC削除
    [Interface.sch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]
2018-01-20 アノテーション修正
    [Interface.sch, RPi_GPIO.sch, Tsubuta-cpu.sch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]
2018-01-20 内部処理を見直し 電源シーケンス見直し バッテリー残量警告追加
2018-01-20 バッテリー残量閾値を見直し
